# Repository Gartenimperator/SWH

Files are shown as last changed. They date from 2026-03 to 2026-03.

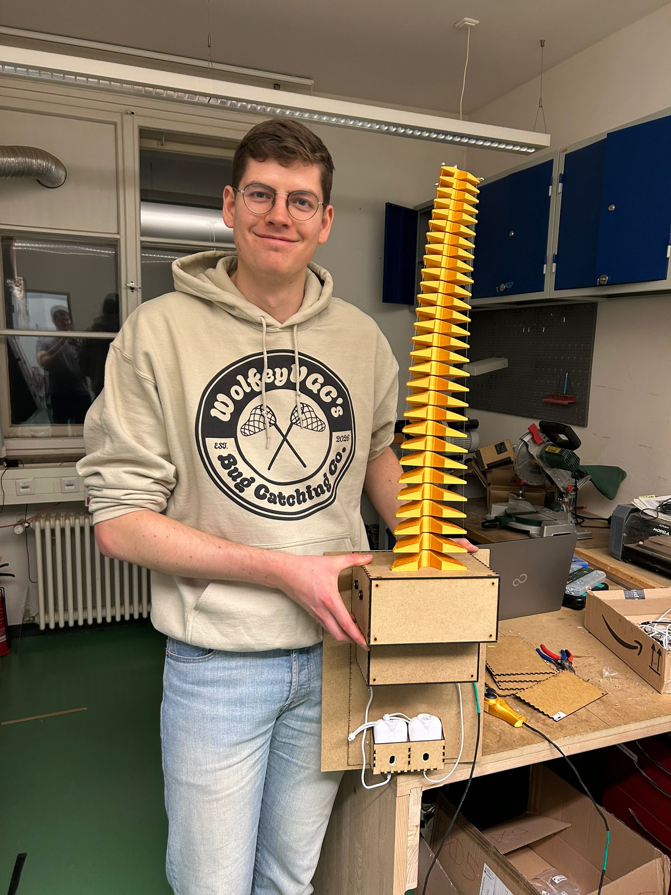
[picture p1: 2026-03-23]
resources/tail_closed_happy.jpeg

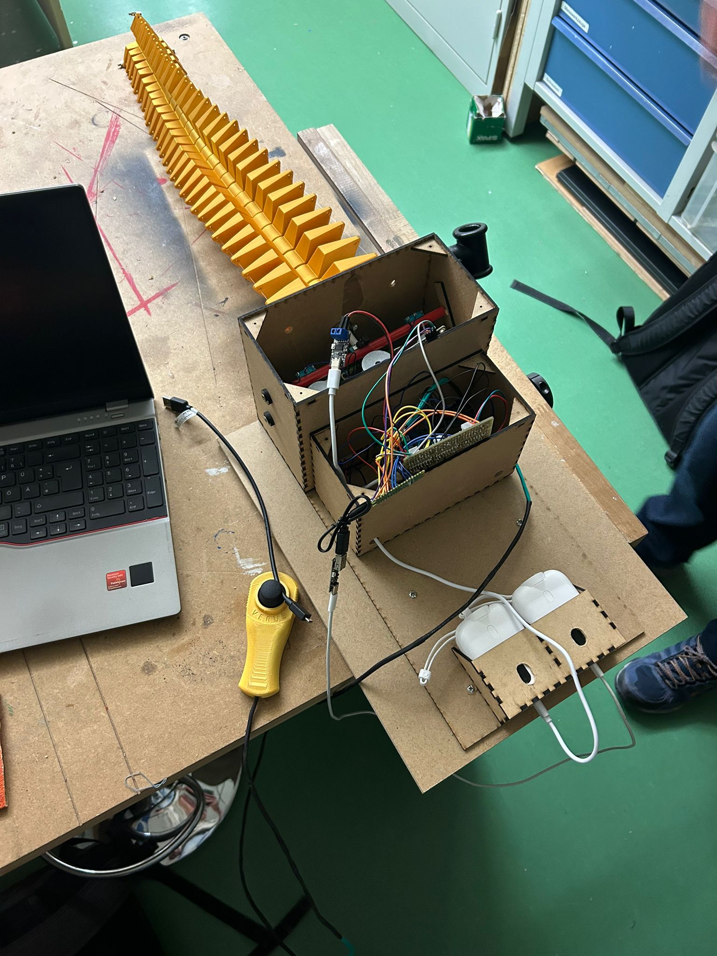
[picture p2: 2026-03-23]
resources/tail_open.jpeg

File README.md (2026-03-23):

# Emotacle User Manual

## Base Handling Rules

- Do NOT let the spine of the Emotacle move unsupported unless it is powered on, in which case the motors will hold it in place.
- Do NOT operate the Emotacle unless it is in vertical orientation. This may cause the motors to move disproportionally.

## Power Up

There are two powerbanks providing power to the emotacle. The left one for the microcontroller Raspberry Pi Pico, the right for the stepper motors moving the Emotacle. 

1. Check that both powerbanks have enough power left
2. Plug in the LEFT power cable to the left powerbank FIRST, to give logic power
3. Plug in the RIGHT power cable to the right powerbank afterwards

If done correctly, the white LED on the Emotacle and the red LED on the black and yellow debug keypad will light up and stay lit up for more than 30 seconds.

<!-- Steps to diagnose -->

## Placement

Place the Emotacle's base module inside a large backpack. It should fit tightly enough that the Emotacle should not shift inside the backpack freely.

## Operation

The Emotacle can be moved in different directions to help the user express themselves by using the onboard gold joystick controller connected to the Emotacle by a cable. The same attachment is also used to change the colors of the multicolor LED on the top.

- Left-to-right will change the direction that the Emotacle will move in
- Up-to-down will move the Emotacle in the desired direction
- Short press in will move to Emotacle to the "Home" position
- Double short press in will cycle the color of the top LED

## Debug Console

For problem diagnosis and maintenance, the debug keypad on the back of the Emotacle can be used for fine-grained control.

- Power button will turn on/off debug mode, indicated by a yellow light from the top LED
- Select individual motors to move with "square", "cross", "circle"
- Reel in/out selected motor (fishing line) with "up" and "down"
- Set center position with "home"

## Shut Down

To stop using the Emotacle, simply follow the steps used to start it backwards.

1. Take the Emotacle out of the backpack
2. Remove the RIGHT cable from the right powerbank FIRST
3. Remove the LEFT cable from the left powerbank afterwards

Once again, make sure to support the spine of the Emotacle when in transit after the power has been turned off.

## Authors
- Kerem Ergur
- Maximilian Hogger
- Victor Jaeschke

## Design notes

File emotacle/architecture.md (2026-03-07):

# Tentacle Arm Controller — Architecture

```mermaid
classDiagram
    class EventBus {
        -list _queue
        -Event _event
        +emit(event, data)
        +listen() tuple
    }

    class ArmController {
        -EventBus _bus
        -LEDController _led
        -CoordinateController _coord
        -float _nx
        -float _ny
        -int _retension_counter
        -dict _tension_buttons
        +bool debug
        +run()
        +calibrate()
        -_move_loop()
        -_execute_deltas(deltas)
        -_retension()
        -_on_joystick(data)
        -_on_home()
        -_on_motor_select(data)
        -_on_motor_pull(data)
        -_on_motor_release(data)
        -_is_under_tension(motor) bool
    }

    class CoordinateController {
        +float azimuth
        +float elevation
        -dict _motor_positions
        +rotate(delta_degrees) dict
        +tilt(delta_elevation) dict
        +home() dict
        +set_center()
        +get_position() dict
        -_move_to(azimuth, elevation) dict
        -_calculate_ideal_positions(azimuth, elevation) dict
        -_compute_slack_factor(elevation) float
    }

    class LEDController {
        -PWM _r
        -PWM _g
        -PWM _b
        -int _mode_idx
        +current_mode
        +run()
        +set_mode(name)
        +next_mode()
        +stop()
    }

    class Joystick {
        -EventBus _bus
        -ADC adc_x
        -ADC adc_y
        -Pin sw
        +float nx
        +float ny
        +bool pressed
        +run()
        -_read_adc(adc) int
        -_normalize(raw) float
    }

    class Gamepad {
        -EventBus _bus
        -I2C i2c
        -str selected_motor
        +run()
        +get_single_pressed() str
    }

    class StepperMotor {
        +str name
        -Pin dir
        -StateMachine sm
        +set_direction(direction)
        +step_async(steps, delay_us)
        +pulse(delay_us)
    }

    class config {
        <<module>>
        MOTOR_ANGLES : x=0° y=120° z=240°
        
        CLOCKWISE : 0
COUNTERCLOCKWISE : 1

STEPS_PER_REV      : 200   
DEFAULT_SPEED_US   : 2000   
INTERLACE_STEP_SIZE : 10 
        ... and more
    }

    ArmController --> EventBus : listens
    ArmController --> LEDController : controls
    ArmController --> CoordinateController : owns
    ArmController ..> StepperMotor : uses via motors module

    Joystick --> EventBus : emits
    Gamepad --> EventBus : emits
```

## Event Flow

```mermaid
sequenceDiagram
    participant J as Joystick
    participant G as Gamepad
    participant B as EventBus
    participant A as ArmController
    participant C as CoordinateController
    participant M as motors module

    J->>B: emit(joystick, {nx, ny})
    G->>B: emit(home / debug_toggle)
    G->>B: emit(motor_select / motor_pull / motor_release)

    B->>A: listen() → event, data
    A->>C: tilt(delta) or rotate(delta)
    C-->>A: motor step deltas dict
    A->>M: move_multiple_steppers(deltas)
```

## Module Overview

| File | Purpose |
|---|---|
| `main.py` | Entry point — wires all components together and starts asyncio tasks |
| `arm_controller.py` | Top-level control logic, joystick/gamepad event handling, retension |
| `coordinate_controller.py` | Spherical coordinate math, motor position tracking |
| `motors.py` | PIO-based stepper motor driver (`StepperMotor`) and module-level move functions |
| `led_controller.py` | Async RGB LED with switchable animation modes |
| `joystick_controller.py` | Reads analog joystick, emits `joystick` events |
| `touchpad_controller.py` | Reads I2C gamepad buttons, emits control events |
| `event_bus.py` | Async queue connecting input controllers to `ArmController` |
| `config.py` | All pin assignments, tuning constants, and motor geometry |

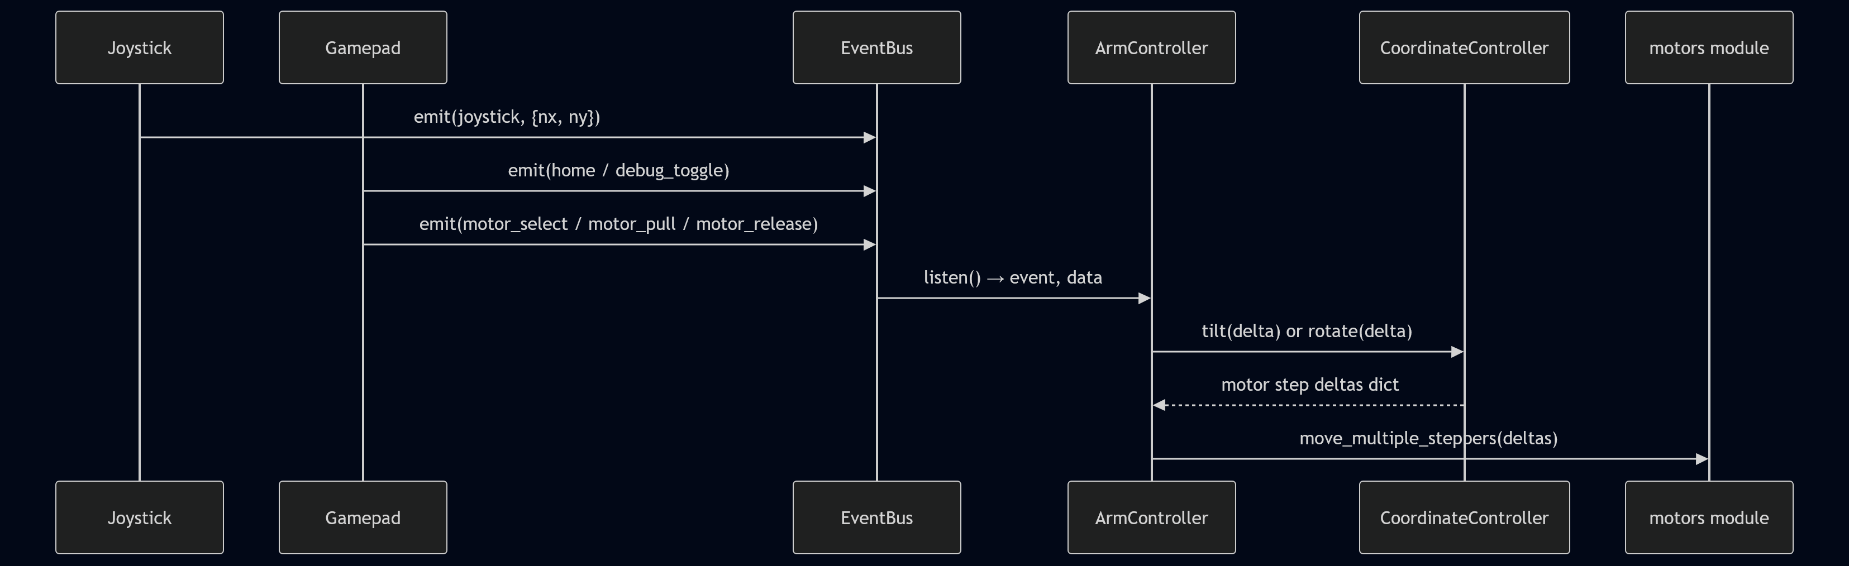
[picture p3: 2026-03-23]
resources/mermaid-diagram-2026-03-19-135446(1).png

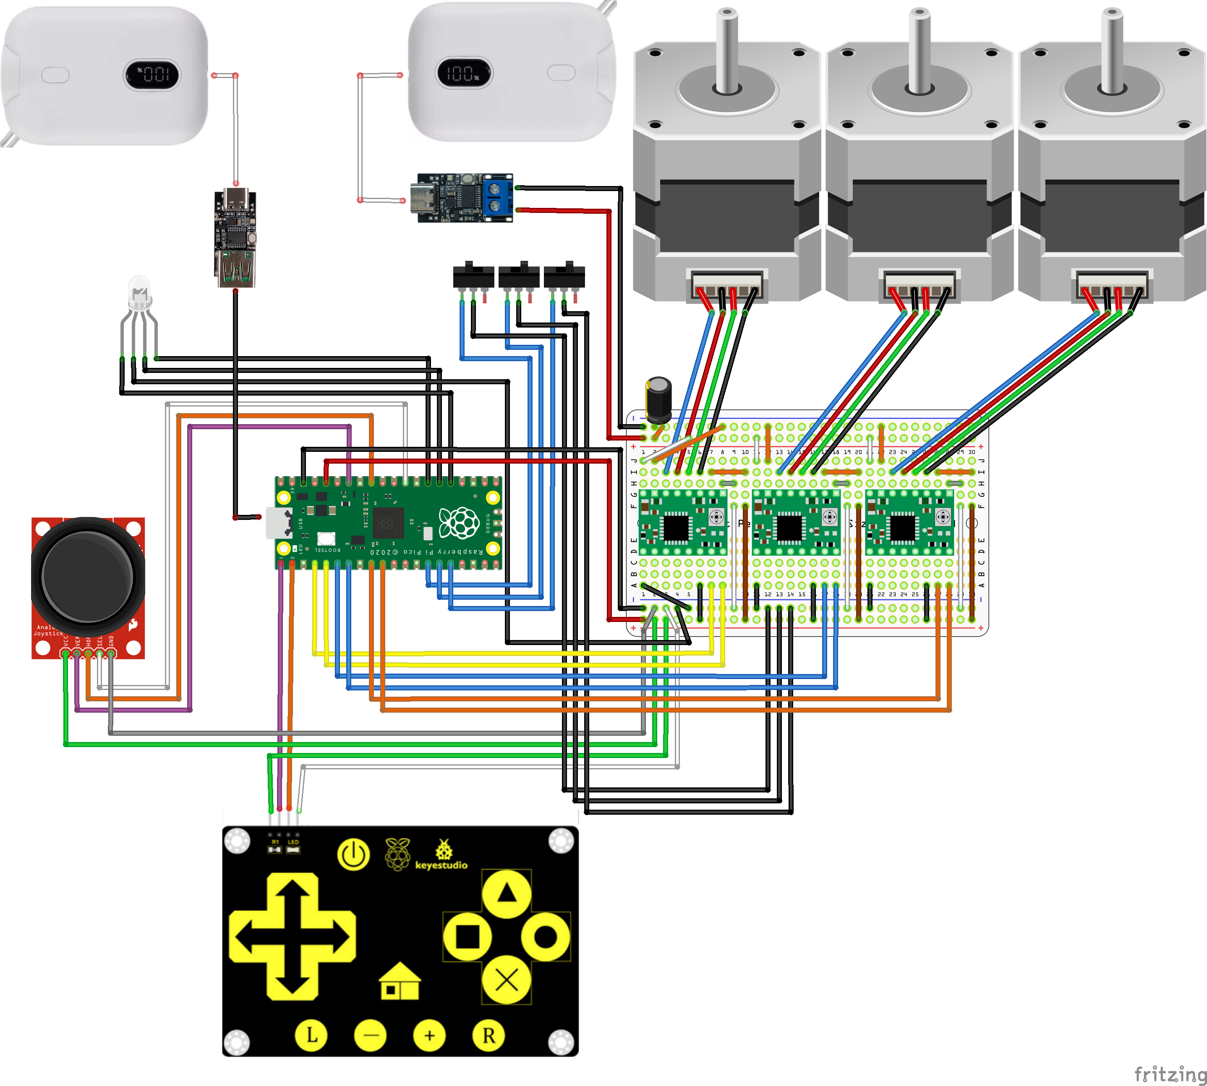
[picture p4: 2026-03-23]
resources/fritzing.png

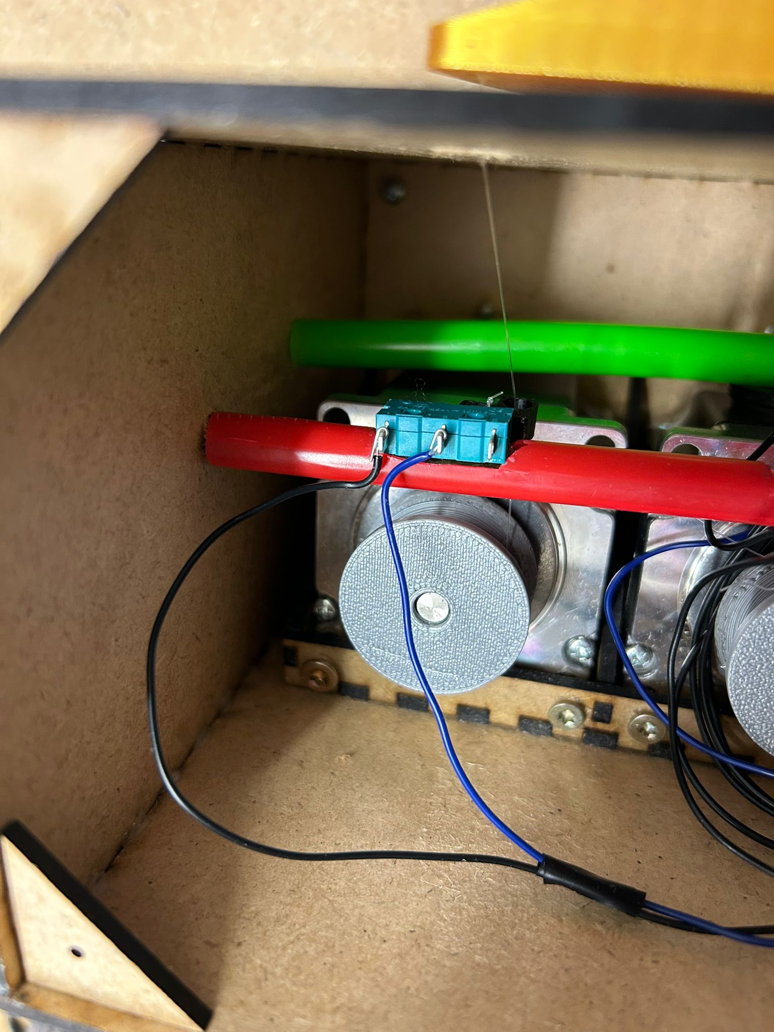
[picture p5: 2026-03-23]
resources/motor_close_up.jpeg

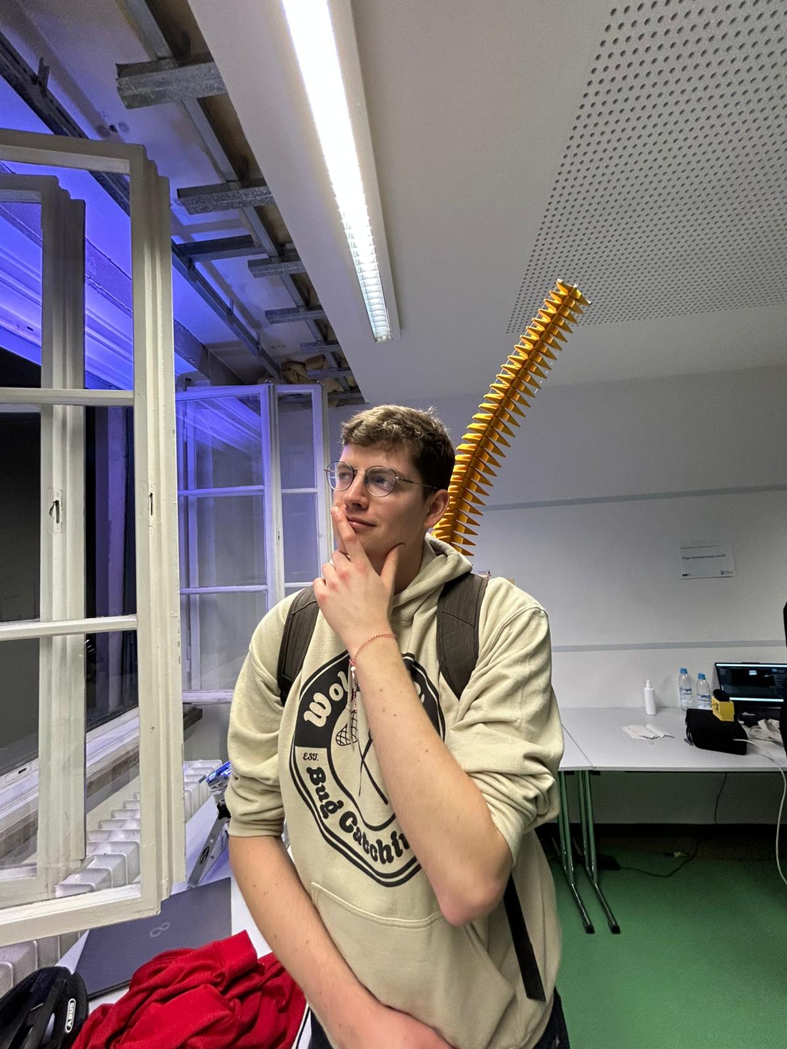
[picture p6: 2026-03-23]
resources/tail_wearing_think.jpeg

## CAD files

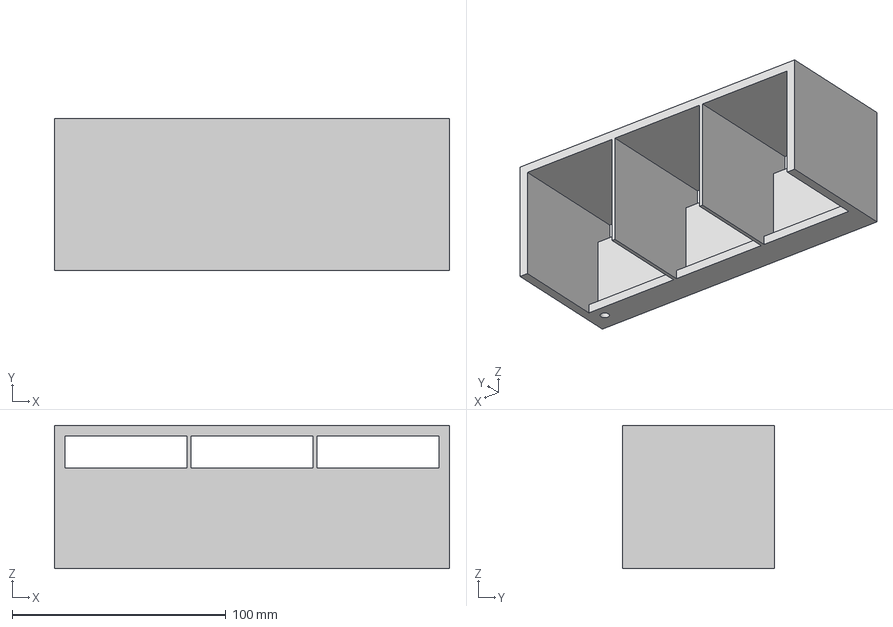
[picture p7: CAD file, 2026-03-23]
resources/Stepper Housing.3mf
185.0 x 71.0 x 67.0 mm

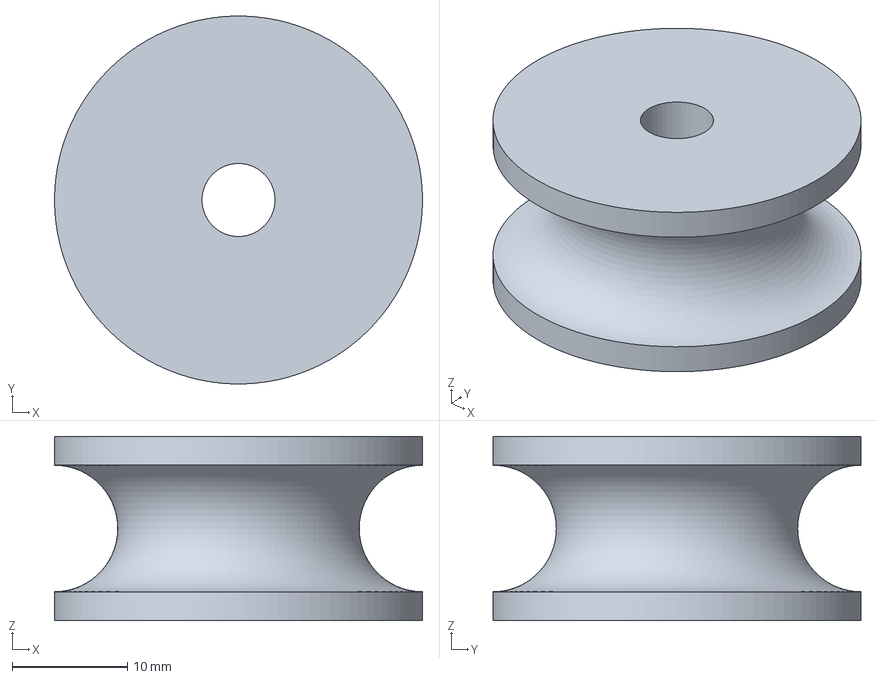
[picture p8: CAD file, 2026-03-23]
resources/Spool.3mf
32.0 x 32.0 x 16.0 mm

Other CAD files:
resources/clicker_hole.gcode.3mf
resources/Spool.f3d
resources/Stepper Housing.f3d

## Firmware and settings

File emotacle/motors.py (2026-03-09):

# Motor control module for Tentacle Arm Controller
# Raspberry Pi Pico W with A4988/DRV8825 drivers
# Uses PIO state machines for precise hardware-timed stepping

from machine import Pin
import rp2
try:
    import uasyncio as asyncio
except ImportError:
    import asyncio
from config import MOTORS, MOTOR_ALIASES, DEFAULT_SPEED_US, INTERLACE_STEP_SIZE

# PIO clock frequency (1MHz = 1 cycle per microsecond for easy timing)
PIO_FREQ = 1_000_000


@rp2.asm_pio(set_init=rp2.PIO.OUT_LOW, autopull=False, fifo_join=rp2.PIO.JOIN_TX)
def stepper_pio():
    """PIO program for precise stepper pulse generation.
    Protocol: Send two values to FIFO:
      1. delay_cycles (half-period in PIO cycles, stored in ISR)
      2. step_count (number of pulses to generate)
    Uses ISR to preserve delay value across the step loop.
    At 1MHz PIO clock, 1 cycle = 1 microsecond.
    """
    wrap_target()
    pull(block)              # Wait for delay value
    mov(isr, osr)            # ISR = delay (preserved)
    pull(block)              # Wait for step count
    mov(x, osr)              # X = step count
    label("step_loop")
    set(pins, 1)             # Step HIGH
    mov(y, isr)              # Y = delay countdown
    label("delay_high")
    jmp(y_dec, "delay_high") # Count down
    set(pins, 0)             # Step LOW
    mov(y, isr)              # Y = delay countdown
    label("delay_low")
    jmp(y_dec, "delay_low")  # Count down
    jmp(x_dec, "step_loop")  # Decrement X and loop if not zero
    wrap()                   # Return to start, wait for next command


class StepperMotor:
    """Wrapper for stepper motor control via PIO state machine."""

    _sm_index = 0  # Track which state machine to use next

    def __init__(self, name, step_pin, dir_pin):
        self.name = name
        self.dir = Pin(dir_pin, Pin.OUT)
        self.dir.value(0)

        # Each motor gets its own PIO state machine
        self.sm = rp2.StateMachine(
            StepperMotor._sm_index,
            stepper_pio,
            freq=PIO_FREQ,
            set_base=Pin(step_pin)
        )
        self.sm.active(1)
        StepperMotor._sm_index += 1

    def set_direction(self, direction):
        """Set motor direction (1 = clockwise, 0 = counterclockwise)."""
        self.dir.value(direction)

    def step_async(self, steps, delay_us):
        """Start stepping without blocking. PIO handles timing in hardware.

        Args:
            steps: Number of steps to execute
            delay_us: Half-period delay in microseconds

        Note: At 1MHz PIO clock, delay_us directly equals PIO cycles.
        The jmp loop adds ~2 cycles overhead per delay, so actual timing
        is very close to requested microseconds.
        """
        if steps == 0:
            return
        # Send delay first, then step count (matches PIO protocol)
        self.sm.put(delay_us)
        self.sm.put(steps)

    async def pulse(self, delay_us):
        """Generate one step pulse with given delay."""
        self.step_async(1, delay_us)
        # Brief wait for single step to complete
        await asyncio.sleep((delay_us * 2 + 10) / 1_000_000)


# Global motor instances
_motors = {}


def init_motors():
    """Initialize all motor instances from config."""
    global _motors
    for name, pins in MOTORS.items():
        _motors[name] = StepperMotor(name, pins['step'], pins['dir'])
    return _motors


def get_motor(motor_id):
    """Get motor by name or alias (x, y, z -> motor1, motor2, motor3)."""
    motor_id = str(motor_id).lower()
    if motor_id in MOTOR_ALIASES:
        motor_id = MOTOR_ALIASES[motor_id]
    return _motors.get(motor_id)


async def move_stepper(motor_id, direction, speed_us, steps):
    """Move a single stepper motor.

    Args:
        motor_id: Motor name or alias ('x', 'y', 'z' or 'motor1', 'motor2', 'motor3')
        direction: 1 for clockwise, 0 for counterclockwise
        speed_us: Pulse delay in microseconds
        steps: Number of steps to move
    """
    motor = get_motor(motor_id)
    if motor is None:
        return False

    motor.set_direction(direction)
    motor.step_async(steps, speed_us)

    # Wait for movement to complete (total time = steps * 2 * delay)
    await asyncio.sleep((steps * speed_us * 2 + 100) / 1_000_000)

    return True


async def move_multiple_steppers(motor_args, speed_us=None, interlace_size=None):
    """Move multiple steppers simultaneously using PIO hardware timing.

    All motors start at the same time and run in parallel via their
    dedicated PIO state machines - no interlacing needed with hardware timing.

    Args:
        motor_args: List of dicts with keys:
            - 'id': Motor name or alias
            - 'direction': 1 for clockwise, 0 for counterclockwise
            - 'steps': Number of steps to move
        speed_us: Pulse delay in microseconds (default from config)
        interlace_size: Ignored (kept for API compatibility)

    Returns:
        True if successful, False otherwise
    """
    if speed_us is None:
        speed_us = DEFAULT_SPEED_US

    if not motor_args:
        return False

    # Resolve motors and set directions
    motors_to_move = []
    max_steps = 0
    for arg in motor_args:
        motor = get_motor(arg['id'])
        if motor is None:
            continue
        motor.set_direction(arg['direction'])
        motors_to_move.append({
            'motor': motor,
            'steps': arg['steps']
        })
        max_steps = max(max_steps, arg['steps'])

    if not motors_to_move:
        return False

    # Start all motors simultaneously - PIO handles timing in hardware
    for m in motors_to_move:
        m['motor'].step_async(m['steps'], speed_us)

    # Wait for longest movement to complete
    await asyncio.sleep((max_steps * speed_us * 2 + 100) / 1_000_000)

    return True


# For testing directly on device
if __name__ == '__main__':
    print("Initializing motors...")
    init_motors()

    print("Testing multi-motor movement...")
    move_multiple_steppers([
        {'id': 'x', 'direction': 0, 'steps': 10},
        {'id': 'y', 'direction': 0, 'steps': 10},
    ], speed_us=2000, interlace_size=10)

    print("Motor test complete.")

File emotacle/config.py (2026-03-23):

# Configuration for Tentacle Arm Controller
# Raspberry Pi Pico W with A4988/DRV8825 drivers

# =============================================================================
# PIN ASSIGNMENTS
# =============================================================================

# Stepper motors (STEP, DIR)
MOTORS = {
    'motor1': {'step': 2, 'dir': 3},
    'motor2': {'step': 4, 'dir': 5},
    'motor3': {'step': 6, 'dir': 7},
}

# Joystick (analog axes + switch)
JOYSTICK_X_PIN  = 28
JOYSTICK_Y_PIN  = 27
JOYSTICK_SW_PIN = 22

# Gamepad / touchpad (I2C)
GAMEPAD_SDA_PIN = 0
GAMEPAD_SCL_PIN = 1

# LED RGB (PWM channels, GND on hardware pin)
LED_RED_PIN   = 19
LED_GREEN_PIN = 20
LED_BLUE_PIN  = 21
# Tension/slack detection buttons (one per motor, pressed = string under tension)
# NOTE: pins 16/17/18 currently overlap with LED pins above — reassign as needed
TENSION_BUTTON_PINS = {'x': 11, 'y': 10, 'z': 12}
#11-left-x 12-middle-z 10-right-y

# Steps pulled per calibration iteration when taking up slack
CALIBRATION_PULL_STEPS = 5

# =============================================================================
# MOTOR SETTINGS
# =============================================================================

MOTOR_ALIASES   = {'x': 'motor1', 'y': 'motor2', 'z': 'motor3'}
CLOCKWISE       = 0
COUNTERCLOCKWISE = 1

STEPS_PER_REV      = 200    # Steps per full revolution (NEMA17)
DEFAULT_SPEED_US   = 2000   # Pulse half-period in microseconds
MIN_SPEED_US       = 100    # Fastest (shortest delay)
MAX_SPEED_US       = 5000   # Slowest (longest delay)
DEFAULT_STEPS      = 100    # Default steps per jog
INTERLACE_STEP_SIZE = 10    # Steps per interlace cycle

# =============================================================================
# COORDINATE CONTROLLER
# =============================================================================

# Motor angular positions (equilateral triangle, 120° apart)
MOTOR_ANGLES = {'x': 60, 'y': 180, 'z': 300}

STEPS_PER_DEGREE     = 5    # Motor steps per degree of tilt (tunable)
ELEVATION_LIMIT      = 50   # Maximum elevation magnitude (±60)
ROTATION_STEP_DEGREES = 5   # Degrees per joystick step
ELEVATION_STEP_UNITS  = 3   # Elevation units per joystick step

# Slack compensation — multiplier applied to release steps (1.0 = no compensation)
# Tune below 1.0 only if the arm physically overshoots during rotation
SLACK_AT_CENTER = 0.6        # Slack factor near 0 elevation
SLACK_AT_LIMIT  = 0.2        # Slack factor at max elevation

# Retension is called every N move_loop iterations to avoid fighting rotation
# while still preventing string uncoiling from prolonged slack
RETENSION_INTERVAL = 1

# =============================================================================
# JOYSTICK CONTROL
# =============================================================================

JOYSTICK_SAMPLE_DELAY = 0.1  # Seconds between ADC reads
JOYSTICK_MIN          = 300  # Physical minimum ADC reading (hardware limit)
JOYSTICK_MAX          = 1024  # Physical maximum ADC reading (hardware limit)
JOYSTICK_CENTER       = 512  # Mid-point of physical range
JOYSTICK_DEADZONE     = 106  # Raw units around centre → output 0 (midpoint between CENTER and MIN)

# =============================================================================
# GAMEPAD CONTROL
# =============================================================================

GAMEPAD_ADDRESS      = 0x57
GAMEPAD_POLL_DELAY   = 0.1  # Seconds between button polls
GAMEPAD_MANUAL_STEPS = 20    # Steps per UP/DOWN button event

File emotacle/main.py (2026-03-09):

# Main entry point for Tentacle Arm Controller
# Raspberry Pi Pico W - physical joystick + gamepad control

try:
    import uasyncio as asyncio
except ImportError:
    import asyncio

from motors import init_motors
from event_bus import EventBus
from arm_controller import ArmController
from led_controller import LEDController
from joystick_controller import Joystick
from touchpad_controller import Gamepad
from machine import Pin

led_onboard = Pin("LED", Pin.OUT)

async def main():
    led_onboard.on()
    print("Initializing motors...")
    init_motors()
    print("Motors initialized.")

    bus = EventBus()
    led = LEDController()

    asyncio.create_task(led.run())
    asyncio.create_task(Joystick(bus).run())
    asyncio.create_task(Gamepad(bus).run())

    arm = ArmController(bus, led)
    await arm.calibrate()
    asyncio.create_task(arm.run())

    print("Tentacle Arm Controller ready.")
    while True:
        await asyncio.sleep(3600)


try:
    asyncio.run(main())
except KeyboardInterrupt:
    print("\nShutting down...")

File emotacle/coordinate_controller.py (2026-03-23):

# Coordinate Controller for Tentacle Arm
# Handles spherical coordinate transformations for the tripod cable-driven mechanism

import math
from config import MOTOR_ANGLES, STEPS_PER_DEGREE, ELEVATION_LIMIT, SLACK_AT_CENTER, SLACK_AT_LIMIT


class CoordinateController:
    """Manages spherical coordinate state and motor position calculations.

    The tentacle arm uses 3 motors positioned at 120 degrees apart (equilateral triangle).
    Each motor controls a tendon. This controller tracks:
    - Azimuth (theta): Direction the tentacle points (0-360 degrees)
    - Elevation: Tilt magnitude from center (0 = centered, positive/negative = tilted up/down)
    """

    def __init__(self):
        self.azimuth = 0.0          # Current azimuth in degrees (0-360)
        self.elevation = 0.0        # Current elevation (arbitrary units)
        self._motor_positions = {'x': 0, 'y': 0, 'z': 0}  # Actual motor positions (with slack applied)

    def rotate(self, delta_degrees):
        """Rotate azimuth by delta_degrees, return motor step deltas.

        Args:
            delta_degrees: Degrees to rotate (positive = counterclockwise from above)

        Returns:
            Dict of motor step deltas {'x': int, 'y': int, 'z': int}
        """
        new_azimuth = (self.azimuth + delta_degrees) % 360
        return self._move_to(new_azimuth, self.elevation)

    def tilt(self, delta_elevation):
        """Change elevation by delta_elevation, return motor step deltas.

        Args:
            delta_elevation: Amount to change elevation (positive = tilt more)

        Returns:
            Dict of motor step deltas {'x': int, 'y': int, 'z': int}
        """
        new_elevation = max(-ELEVATION_LIMIT, min(ELEVATION_LIMIT, self.elevation + delta_elevation))
        return self._move_to(self.azimuth, new_elevation)

    def home(self):
        """Return to center position (0, 0).

        Directly reverses actual motor positions — no slack model needed
        since we're returning to the known physical center.

        Returns:
            Dict of motor step deltas {'x': int, 'y': int, 'z': int}
        """
        deltas = {}
        for motor in ['x', 'y', 'z']:
            deltas[motor] = -self._motor_positions[motor]
        self.azimuth = 0.0
        self.elevation = 0.0
        self._motor_positions = {'x': 0, 'y': 0, 'z': 0}
        return deltas

    def set_center(self):
        """Mark current physical position as the new center (origin).

        Resets coordinate state to (0, 0) without moving motors.
        Called after user manually calibrates the tentacle position.
        """
        self.azimuth = 0.0
        self.elevation = 0.0
        self._motor_positions = {'x': 0, 'y': 0, 'z': 0}
        print(self)

    def get_position(self):
        """Get current coordinate state.

        Returns:
            Dict with 'azimuth', 'elevation', 'motor_positions', and 'slack_factor'
        """
        return {
            'azimuth': self.azimuth,
            'elevation': self.elevation,
            'motor_positions': self._motor_positions.copy(),
            'slack_factor': self._compute_slack_factor(self.elevation)
        }

    def _compute_slack_factor(self, elevation):
        """Compute non-linear slack factor based on elevation magnitude.

        Interpolates linearly from SLACK_AT_CENTER (near 0) to
        SLACK_AT_LIMIT (at max elevation).

        Args:
            elevation: Current elevation value

        Returns:
            Slack factor between SLACK_AT_LIMIT and SLACK_AT_CENTER
        """
        t = min(abs(elevation) / ELEVATION_LIMIT, 1.0)
        return SLACK_AT_CENTER - (SLACK_AT_CENTER - SLACK_AT_LIMIT) * t

    def _move_to(self, new_azimuth, new_elevation):
        """Calculate and apply movement to new position.

        Computes deltas from actual motor positions to ideal target.
        Slack is applied per-motor: only when a release would take
        that motor further from its rest position (0). When a motor
        releases toward 0, the core helps spring back — no slack needed.

        Args:
            new_azimuth: Target azimuth in degrees
            new_elevation: Target elevation

        Returns:
            Dict of motor step deltas {'x': int, 'y': int, 'z': int}
        """
        ideal_new = self._calculate_ideal_positions(new_azimuth, new_elevation)
        slack = self._compute_slack_factor(new_elevation)

        deltas = {}
        for motor in ['x', 'y', 'z']:
            # Delta from actual position to ideal target
            delta = ideal_new[motor] - self._motor_positions[motor]
            # Apply slack only when releasing AND moving further from rest (0)
            if delta > 0:
                new_pos = self._motor_positions[motor] + delta
                if abs(new_pos) > abs(self._motor_positions[motor]):
                    delta = int(delta * slack)
            deltas[motor] = delta

        # Update state — track actual motor positions
        self.azimuth = new_azimuth
        self.elevation = new_elevation
        for motor in ['x', 'y', 'z']:
            self._motor_positions[motor] += deltas[motor]

        return deltas

    def seek(self, target_azimuth, target_elevation):
        """Move toward a target (azimuth, elevation) in one step.

        Used by the 8-position joystick steering model to jump directly to the
        target rather than nudging incrementally.

        Args:
            target_azimuth: Target azimuth in degrees (0-360)
            target_elevation: Target elevation (clamped to ±ELEVATION_LIMIT)

        Returns:
            Dict of motor step deltas {'x': int, 'y': int, 'z': int}
        """
        target_elevation = max(-ELEVATION_LIMIT, min(ELEVATION_LIMIT, target_elevation))
        return self._move_to(target_azimuth, target_elevation)

    def _calculate_ideal_positions(self, azimuth, elevation):
        """Calculate ideal motor positions (pure geometry, no slack).

        Uses the formula: position = elevation * cos(azimuth - motor_angle)

        Args:
            azimuth: Direction in degrees (0-360)
            elevation: Tilt magnitude

        Returns:
            Dict of motor positions {'x': int, 'y': int, 'z': int}
        """
        positions = {}
        azimuth_rad = math.radians(azimuth)

        for motor, angle in MOTOR_ANGLES.items():
            angle_rad = math.radians(angle)
            position = elevation * math.cos(azimuth_rad - angle_rad) * STEPS_PER_DEGREE
            positions[motor] = int(position)

        return positions


# Global instance for the application
_controller = None


def get_controller():
    """Get or create the global CoordinateController instance."""
    global _controller
    if _controller is None:
        _controller = CoordinateController()
    return _controller

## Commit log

2026-01-22 feat: First iteration of code. Working Webserver on micropico that allows simple control of motors.
2026-01-22 feat: Added a movement system based on a cicular coordinate system which is tracked by steps moved by each specific motor
2026-02-16 Introduced Websocket (WIP) for better control. Added PIO statemachine instead of sleep in stepper /motor controller.
2026-02-16 Fixed But in assembly code, motors run correctly now
    [motors.py]
2026-02-16 slack is now handled internally in the coordinate_controller.py. WIP Still not working fully satisfactory
    [config.py, coordinate_controller.py]
2026-03-23 Add ressources; Spool
    [Spool.3mf, Spool.f3d]
2026-03-23 Add resources; Stepper Housing
    [Stepper Housing.3mf, Stepper Housing.f3d]
2026-03-23 added clicker code, removed test file
    [clicker_hole.gcode.3mf]
